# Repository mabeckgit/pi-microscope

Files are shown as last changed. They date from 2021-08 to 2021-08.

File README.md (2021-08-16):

# pi-microscope

The pi-microscope is a hobby project of mine where I design and program a digital microscope. The core of the microscope is a Raspberry Pi to run the application together with the Raspberry Pi camera module. To achieve magnification I use a spare macro-lens from the [Foldscope project](https://www.foldscope.com/), which in itself is amazing and you should check it out. The hardware are 3d-printed parts that allow me together with some stepper motors to move the camera in XYZ with respect to the object. 

The bill of materials is not complete, yet, as the project is still under development. Indeed, I am currently using stepper motors salvaged from an old fax machine -- so not really off the shelf material. Once the design is polished I will list a full bill of materials here. Here is what I have used so far: 
* [Raspberry Pi 4 Model B](https://www.raspberrypi.org/products/raspberry-pi-4-model-b/)
* [2 Adafruit motor controller HATs] (https://learn.adafruit.com/adafruit-dc-and-stepper-motor-hat-for-raspberry-pi)
* [A Pololu DRV8825 Stepper Motor Driver] (https://www.pololu.com/product/2133)
* 3 stepper motors (salvaged from fax machine)
* A short piece of LED-strip for illumination of the sample. Any couple of LEDs (say 6 bright ones) will do really. 

Similarly the list of CAD drawings is not complete, as I will likely have to adjust the frame to off the shelf motors. I do include the CAD drawings anyways, as not all of them are specific to the motors and they might be of use in your own design. I will update the drawing files as I go along.

Here is an image of the current iteration.

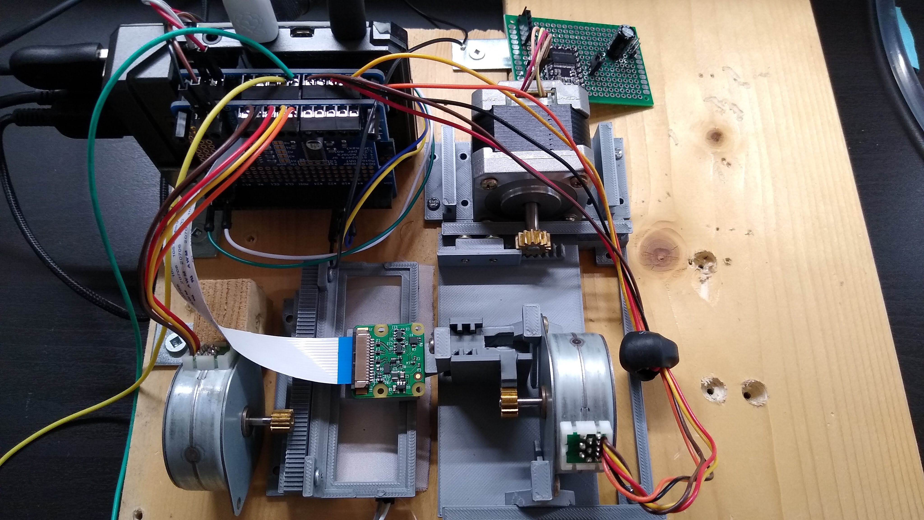
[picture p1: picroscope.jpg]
Picroscope


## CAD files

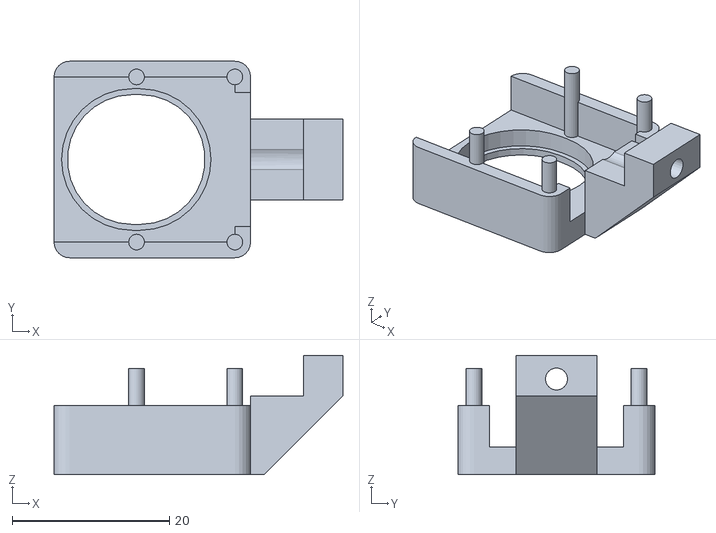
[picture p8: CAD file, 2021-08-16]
Drawings/camera-front_mk3.stl
36.7 x 25.0 x 15.1

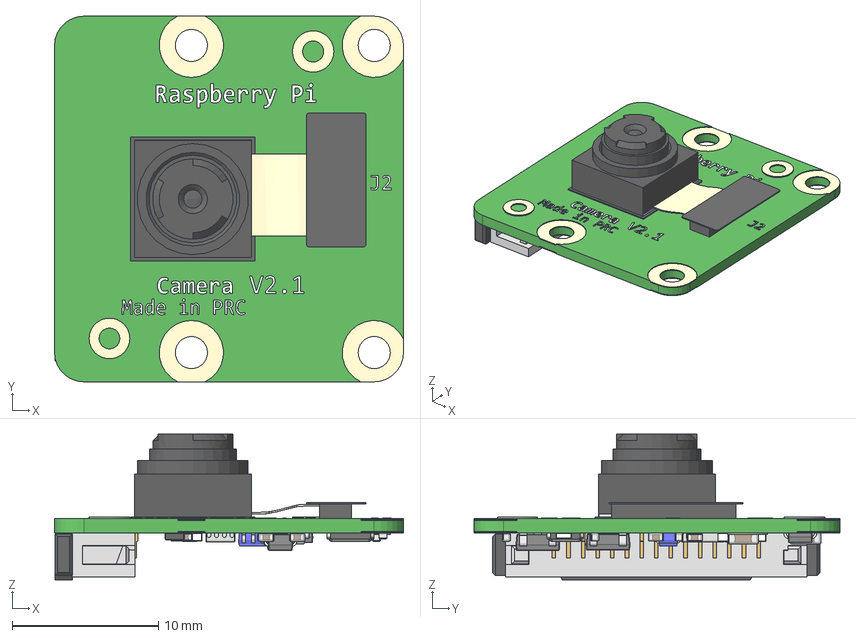
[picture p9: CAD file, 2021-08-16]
Drawings/camera_module/OTHER_FORMATS/RspCameraMia.stp
23.9 x 25.0 x 9.96 mm
PicameraPCB
OVA5647_Housing
OVA5647_Lens_FOV
ribbon_cam
CCD
CAPC-0805-T0.75-BN x 2
CAPC-0402-T0.55-BN x 10
RESC-0402 x 3
RESC-0603 x 2
RESC-1210
c-1-1734248-5-e-raspberry_display
SOT23-5 x 3
KX7 SMD Quartz Crystal Resonator 3.2x2.5mm
c6aaa
4pin_smd x 3

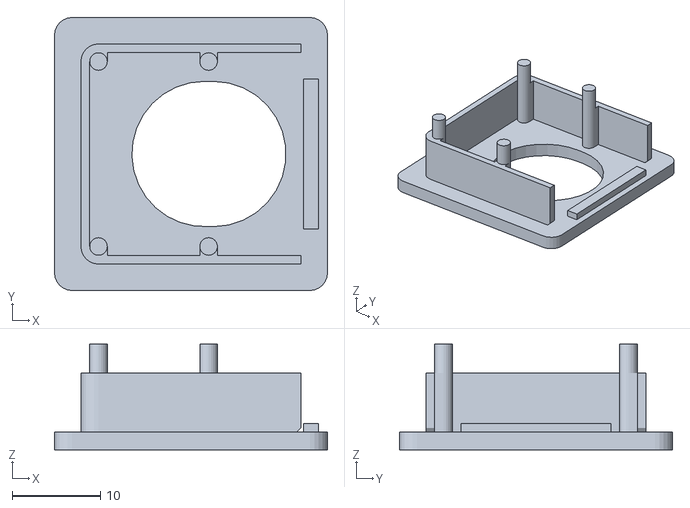
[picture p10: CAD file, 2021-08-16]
Drawings/camera-front.stl
31.0 x 31.0 x 12.0

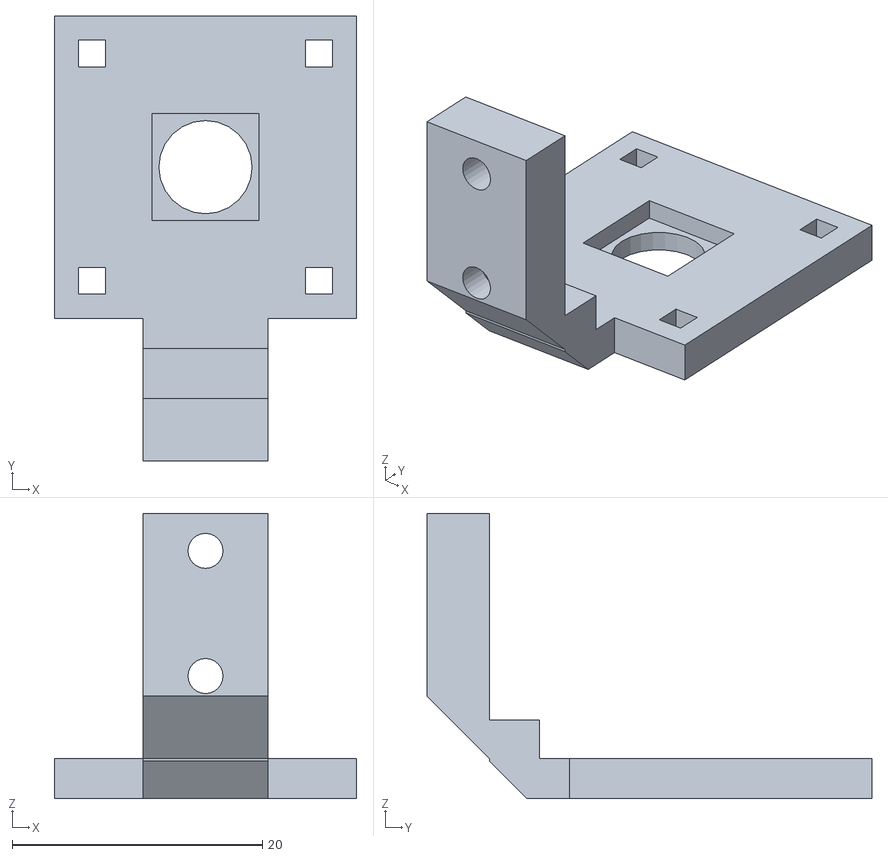
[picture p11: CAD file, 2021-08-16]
Drawings/cameraholder1.stl
24.2 x 35.5 x 22.8

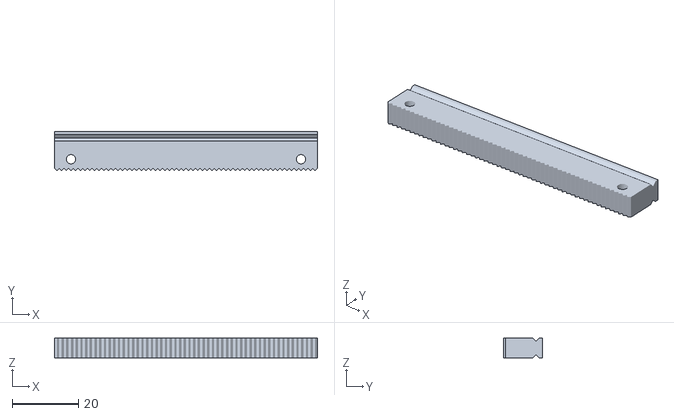
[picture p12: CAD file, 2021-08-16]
Drawings/Small_Toothed_Rod.stl
79.5 x 11.9 x 6.00

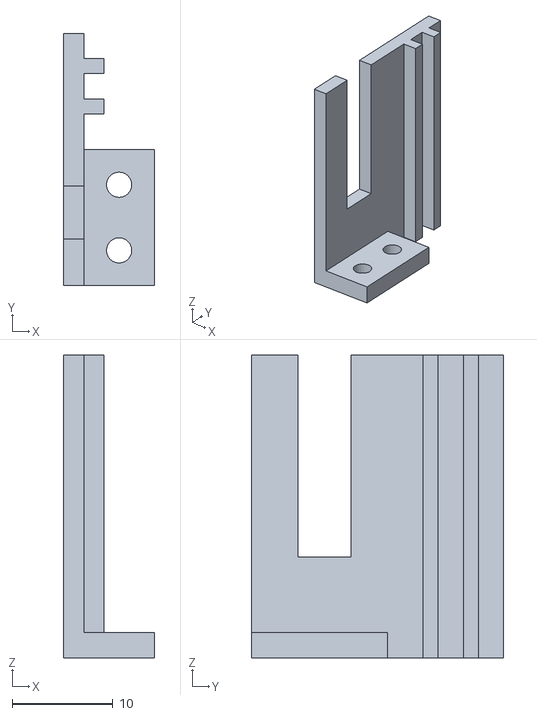
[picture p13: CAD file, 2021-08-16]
Drawings/Y-Tower-Left.stl
9.00 x 25.0 x 30.0

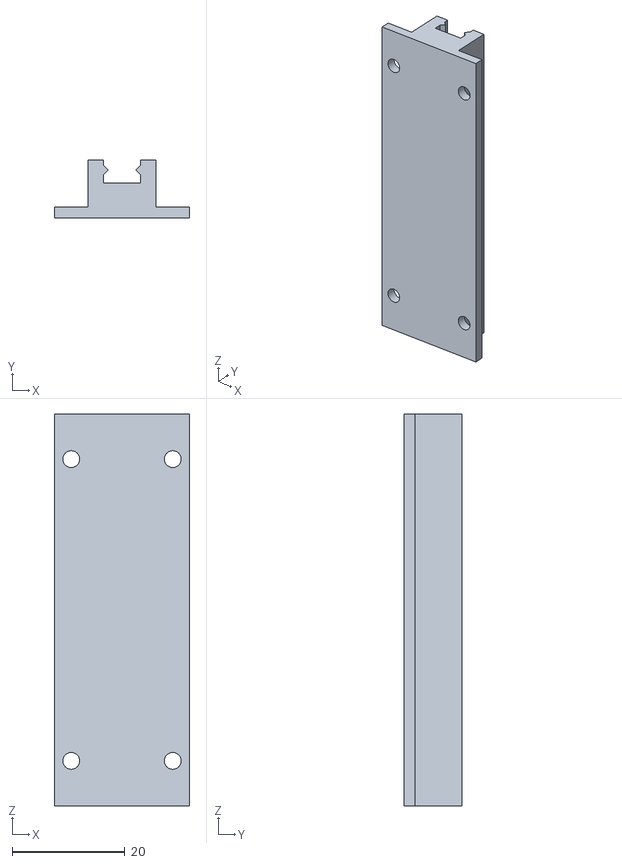
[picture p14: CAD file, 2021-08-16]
Drawings/Guidance-Rail.stl
24.0 x 10.3 x 69.5

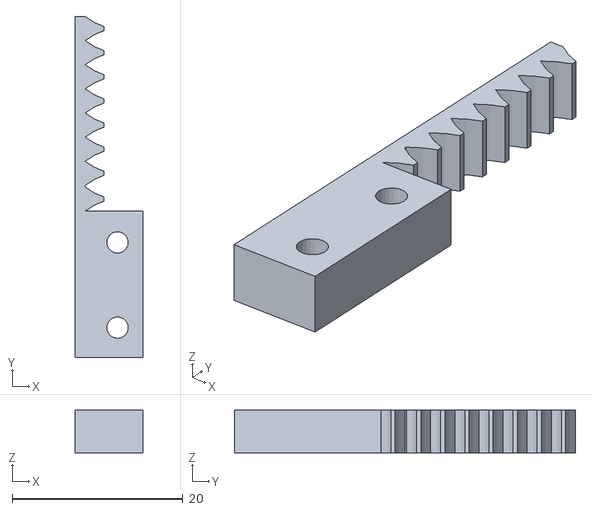
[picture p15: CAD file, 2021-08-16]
Drawings/X-tooth.stl
8.00 x 40.0 x 5.00

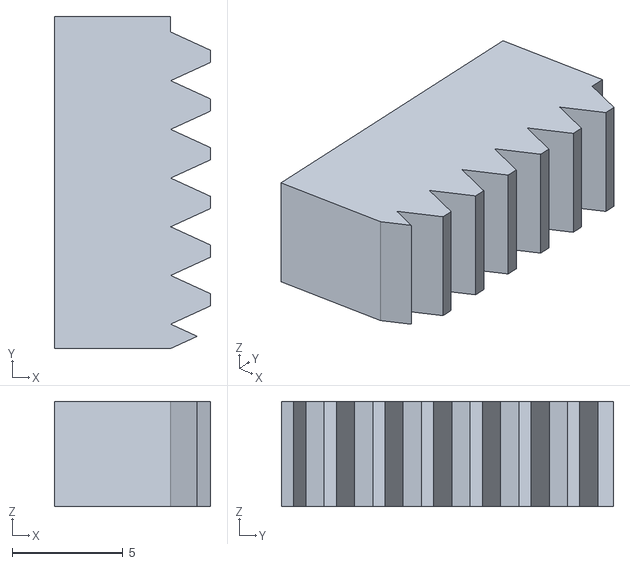
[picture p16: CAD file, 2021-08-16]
Drawings/Z-tooth-test.stl
7.05 x 15.0 x 4.75

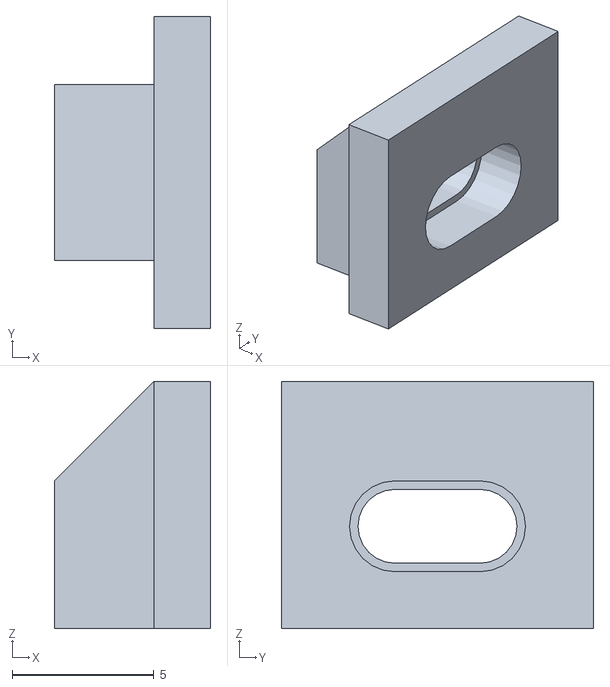
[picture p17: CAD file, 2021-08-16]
Drawings/baseplate-test.stl
5.50 x 11.0 x 8.70

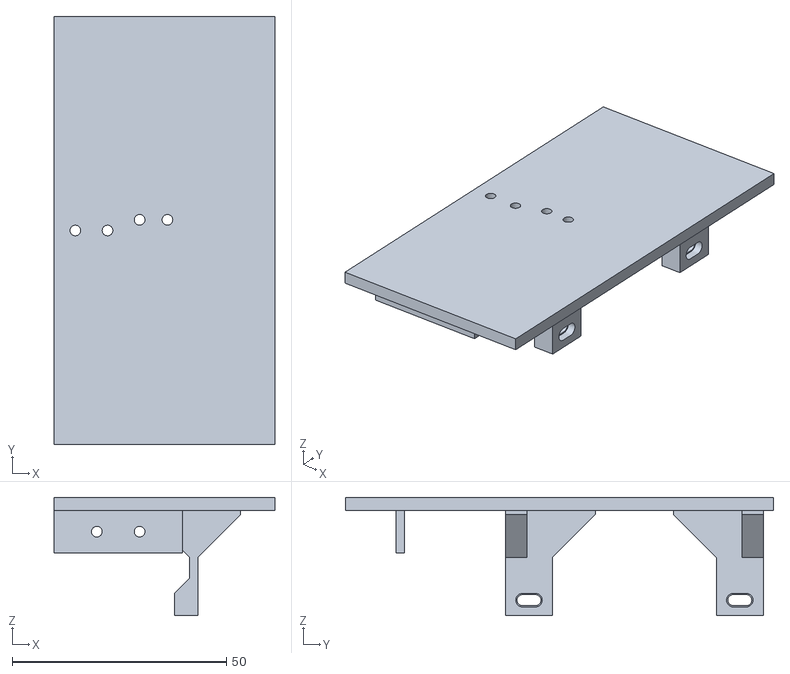
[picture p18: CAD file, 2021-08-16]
Drawings/Baseplate.stl
51.6 x 100.0 x 27.6

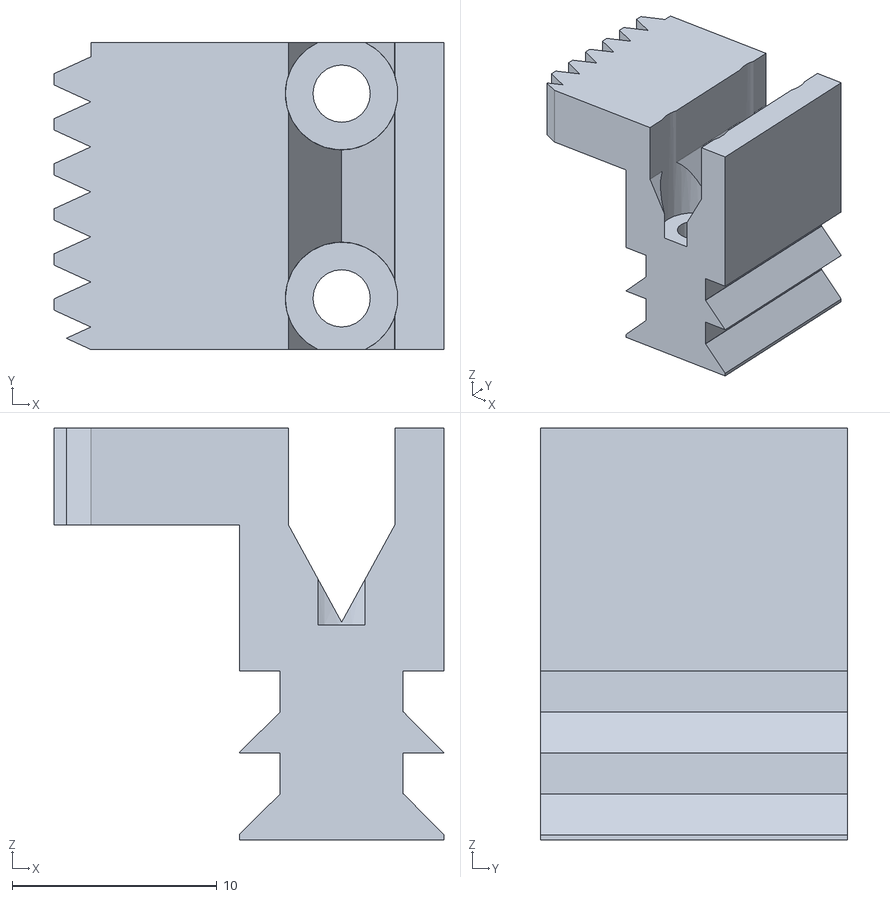
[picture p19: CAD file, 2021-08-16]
Drawings/Z-Carrier.stl
19.1 x 15.0 x 20.1

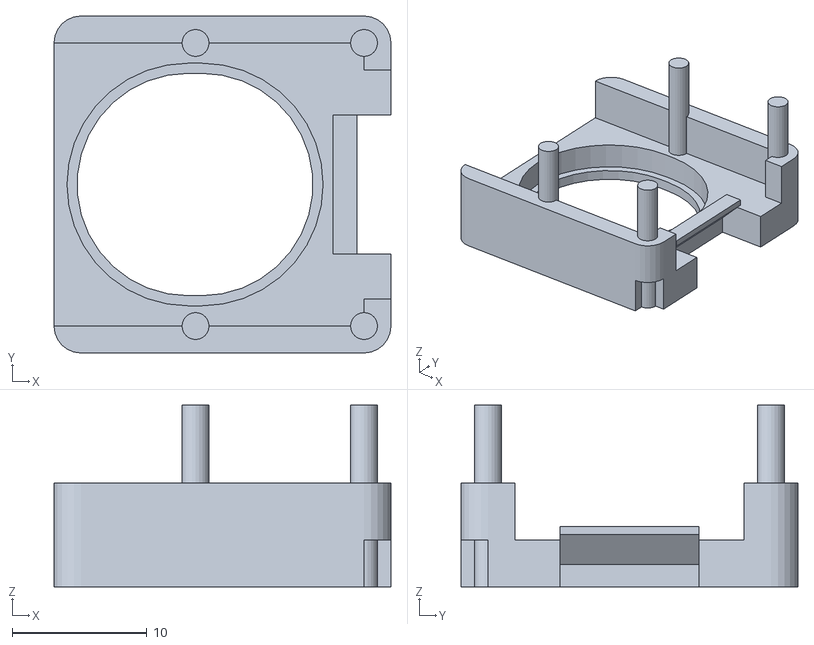
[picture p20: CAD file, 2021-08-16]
Drawings/camera-front_mk2.stl
25.0 x 25.0 x 13.5

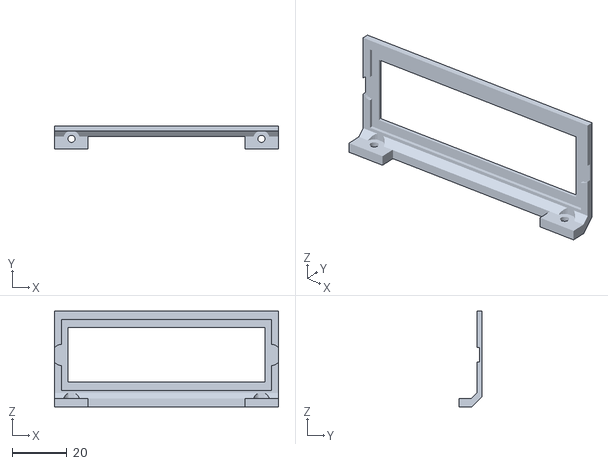
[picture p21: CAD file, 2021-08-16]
Drawings/Glass-holder.stl
82.0 x 8.60 x 35.0

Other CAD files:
Drawings/Y-Tower.dwg
Drawings/cameraholder2.stl
Drawings/Baseplate_Rails.stl
Drawings/Large_Toothed_Rod.stl
Drawings/Baseplate.dwg
Drawings/Baseplate_Rails.dwg
Drawings/Camera-Clip.dwg
Drawings/Camera-Clip.stl
Drawings/Camera-back.dwg
Drawings/Camera-back.stl
Drawings/Glass-Holder.dwg
Drawings/Guidance-Rail-Flat.dwg
Drawings/Guidance-Rail-Flat.stl
Drawings/Guidance-Rail.dwg
Drawings/Large_Toothed_Rod.dwg
Drawings/Small_Toothed_Rod.dwg
Drawings/X-tooth.dwg
Drawings/Y-Tower-Right.stl
Drawings/Z-tooth-test.dwg
Drawings/baseplate-test.dwg
Drawings/camera-front.dwg
Drawings/camera-front_mk2.dwg
Drawings/camera-front_mk3.dwg
Drawings/camera_module/4pin_smd.ipt
Drawings/camera_module/70521906.iam
Drawings/camera_module/70521906_01.ipt
Drawings/camera_module/70521906_02.ipt
Drawings/camera_module/70521906_03.ipt
Drawings/camera_module/70521906_04.ipt
Drawings/camera_module/70521906_05.ipt
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

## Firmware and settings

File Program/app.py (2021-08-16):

#!/usr/bin/env python
from importlib import import_module
import os
from flask import Flask, render_template, Response, request

from Controller import Controller

# import camera driver
if os.environ.get('CAMERA'):
    Camera = import_module('camera_' + os.environ['CAMERA']).Camera
else:
    from camera import Camera

# Raspberry Pi camera module (requires picamera package)
# from camera_pi import Camera

# Setup motor controller
ctrl = Controller()

app = Flask(__name__)


@app.route('/')
def index():
    """Video streaming home page."""
    return render_template('index.html')


def gen(camera):
    """Video streaming generator function."""
    while True:
        frame = camera.get_frame()
        yield (b'--frame\r\n'
               b'Content-Type: image/jpeg\r\n\r\n' + frame + b'\r\n')


@app.route('/video_feed')
def video_feed():
    """Video streaming route. Put this in the src attribute of an img tag."""
    return Response(gen(Camera()),
                    mimetype='multipart/x-mixed-replace; boundary=frame')


@app.route('/link1')
def link1():
    """Testing a link"""
    print("Link 1 was clicked")
    return render_template('index.html')


@app.route('/ajax', methods=['POST'])
def ajax():
    """Testing AJAX"""
    print("AJAX received")
    print(request.form["Button"])
    ctrl.readCommand(request.form["Button"])
    return Response("server response")


if __name__ == '__main__':
    app.run(host='0.0.0.0', threaded=True)

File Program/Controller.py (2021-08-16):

# -*- coding: utf-8 -*-
"""
Created on Fri Apr  3 20:56:24 2020

@author: M
"""

import pigpio
import os
import time
import board
from adafruit_motor import stepper
from adafruit_motorkit import MotorKit


class PeripheryException(Exception):
    pass


class Controller:
    def __init__(self):
        try:
            os.system("sudo pigpiod")

            time.sleep(1)
            self.pi = pigpio.pi()
            if self.pi.connected:
                print("GPIO initialized")
            else:
                raise PeripheryException
        except PeripheryException:
            print("Failed to initialize GPIO. Probably already running")
            raise
        # Initialize HAT-controlled steppers and light
        self.kit = MotorKit(i2c=board.I2C())
        self.kit2 = MotorKit(i2c=board.I2C(), address=0x061)

        self.kit.stepper1.release() # not connected
        self.kit.stepper2.release() # X-axis stepper
        self.kit2.stepper1.release() # Z-axis stepper
        self.kit2.motor3.throttle = 0.0 # Lights

        # Initialize Y-stepper
        self.direction_pin = 18
        self.pi.set_mode(self.direction_pin, pigpio.OUTPUT)
        self.step_pin = 17
        self.pi.set_mode(self.step_pin, pigpio.OUTPUT)
        self.pi.write(self.direction_pin, 0)
        self.pi.write(self.step_pin, 0)
        self.sleep_pin = 27
        self.pi.set_mode(self.sleep_pin, pigpio.OUTPUT)
        self.pi.write(self.sleep_pin, 0)

        self.speed = 4

    def readCommand(self, cmd):
        if cmd == "up":
            self.moveY(down=False)
        elif cmd == "down":
            self.moveY(down=True)
        elif cmd == "left":
            self.moveX(left=True)
        elif cmd == "right":
            self.moveX(left=False)
        elif cmd == "plus":
            self.moveZ(down=False)
        elif cmd == "minus":
            self.moveZ(down=True)
        elif cmd == "brighten":
            self.increaseLight()
        elif cmd == "dim":
            self.decreaseLight()
        elif cmd == "fasten":
            self.increaseSpeed()
        elif cmd == "slow":
            self.decreaseLight()

    def moveX(self, left: bool):
        if left:
            for i in range(16*self.speed):
                self.kit.stepper2.onestep(direction=stepper.BACKWARD,
                                          style=stepper.MICROSTEP)
        else:
            for i in range(16*self.speed):
                self.kit.stepper2.onestep(direction=stepper.FORWARD,
                                          style=stepper.MICROSTEP)
        self.kit.stepper2.release()

    def moveY(self, down: bool):
        if down:
            for i in range(self.speed*16):
                self.kit2.stepper1.onestep(direction=stepper.BACKWARD,
                                           style=stepper.MICROSTEP)
        else:
            for i in range(self.speed*16):
                self.kit2.stepper1.onestep(direction=stepper.FORWARD,
                                           style=stepper.MICROSTEP)
        self.kit2.stepper1.release()

    def moveZ(self, down: bool):
        self.pi.write(self.sleep_pin, 1)
        for step in range(self.speed*32):
            self.pi.write(self.step_pin, 1)
            time.sleep(0.001)
            self.pi.write(self.step_pin, 0)
            time.sleep(0.001)
        self.pi.write(self.sleep_pin, 0)

    def increaseLight(self):
        self.kit2.motor3.throttle = min(1.0, self.kit2.motor3.throttle + 0.25)

    def decreaseLight(self):
        self.kit2.motor3.throttle = max(0.0, self.kit2.motor3.throttle - 0.25)

    def increaseSpeed(self):
        self.speed = min(15, self.speed+1)

    def decreaseSpeed(self):
        self.speed = max(1, self.speed-1)

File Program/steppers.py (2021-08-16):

# SPDX-FileCopyrightText: 2021 ladyada for Adafruit Industries
# SPDX-License-Identifier: MIT

import board
from adafruit_motor import stepper
from adafruit_motorkit import MotorKit
import time

kit = MotorKit(i2c=board.I2C())
kit2 = MotorKit(i2c=board.I2C(), address=0x061)

kit.stepper1.release()
kit.stepper2.release()
"""
kit2.motor3.throttle = 0.25
time.sleep(1.0)
kit2.motor3.throttle = 0.5
time.sleep(1.0)
kit2.motor3.throttle = 0.75
time.sleep(1.0)

time.sleep(1.0)
"""
#kit2.motor3.throttle = 1.0

kit.stepper2.release()
timing3 = 0*16
timing2 = 4*16
left = 0
down = 0
print("Microsteps")

if left == 1:
    for i in range(timing2):
        kit.stepper2.onestep(direction=stepper.BACKWARD, style=stepper.MICROSTEP)
    time.sleep(0.2)
else: 
    for i in range(timing2):
        kit.stepper2.onestep(direction=stepper.FORWARD, style=stepper.MICROSTEP)
    time.sleep(0.2)
print("Interleaved coil steps")
if down == 1:
    for i in range(timing3):
        kit2.stepper1.onestep(direction=stepper.BACKWARD, style=stepper.MICROSTEP)
else:
    for i in range(timing3):
        kit2.stepper1.onestep(direction=stepper.FORWARD, style=stepper.MICROSTEP)
kit.stepper2.release()
kit2.stepper1.release()
